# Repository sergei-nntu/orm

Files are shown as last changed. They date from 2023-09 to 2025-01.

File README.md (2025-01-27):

# ORM
Open Robotic Manipulator

# Arduino
Source code: `src/arduino`
Contains the firmware that needs to be installed to Arduino controller.

# Python Library
Soruce code: `src/python`
Contains the python library that allows to communicate with Arduino controller using USB Serial interface. 

# Mechanics
STL Files: `mechanics/ORM-1. PT1/`

# Tests
To run the server tests, use the following command:

```bash
pytest -v

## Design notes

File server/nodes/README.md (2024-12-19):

# ROS 2 Nodes Directory

This directory contains various ROS 2 nodes, which are essential components of the ROS 2 (Robot Operating System) framework. Each node is a standalone executable that performs specific tasks in a robotic system.

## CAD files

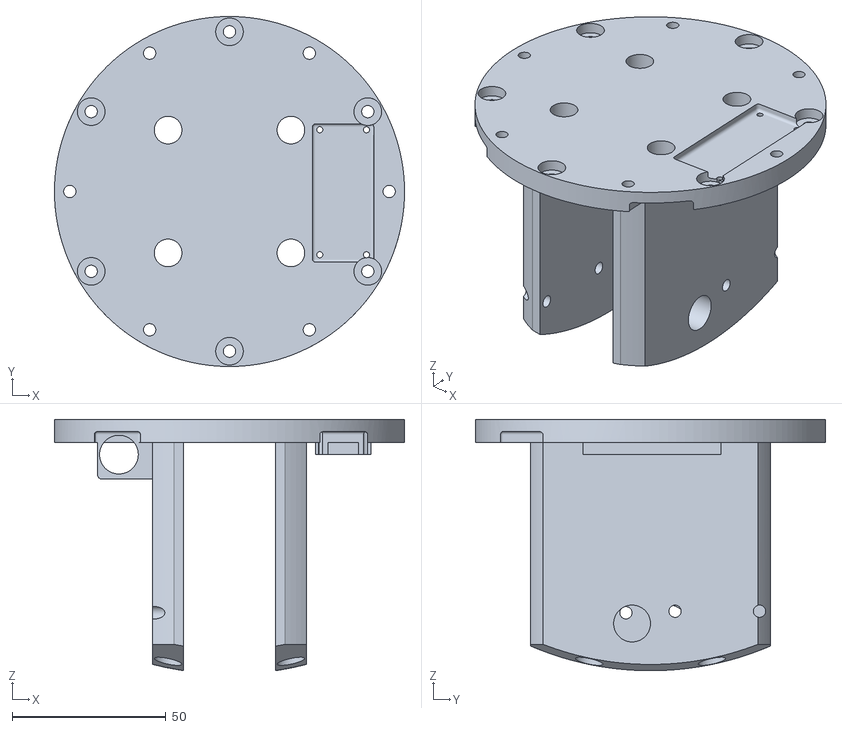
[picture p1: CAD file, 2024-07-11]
mechanics/9_15_3.stl
114.0 x 114.0 x 81.9

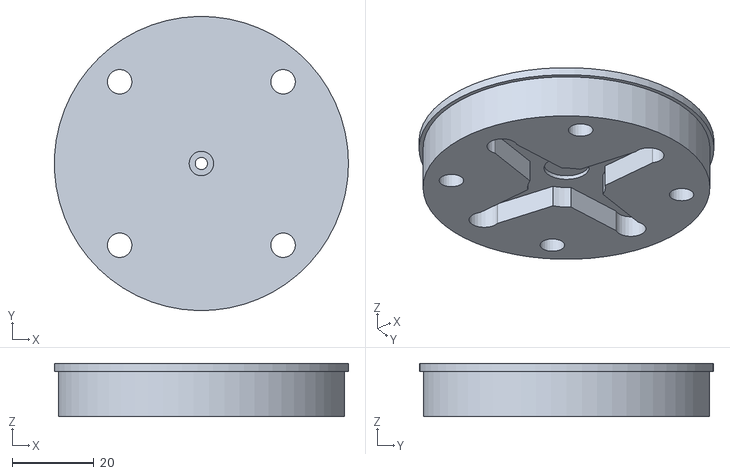
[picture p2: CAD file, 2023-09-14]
mechanics/ORM-1. PT1/15_2_3.stl
71.9 x 72.0 x 13.0

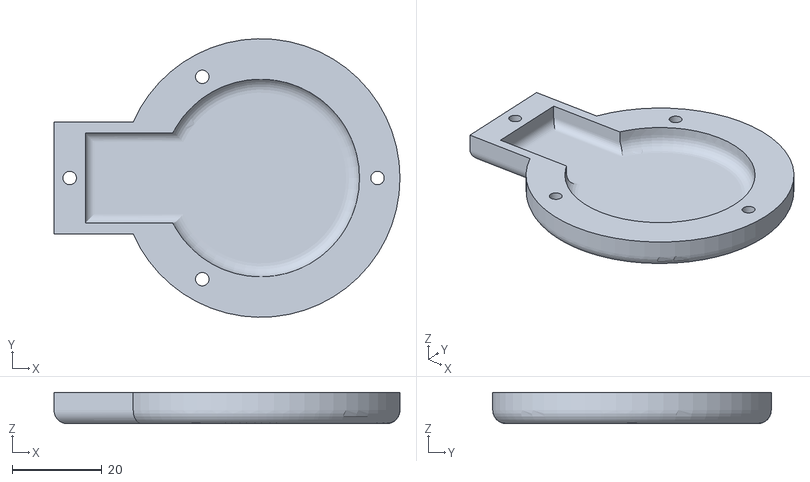
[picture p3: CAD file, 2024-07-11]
mechanics/ORM-1. PT2/14_4_3.stl
77.0 x 62.0 x 7.00

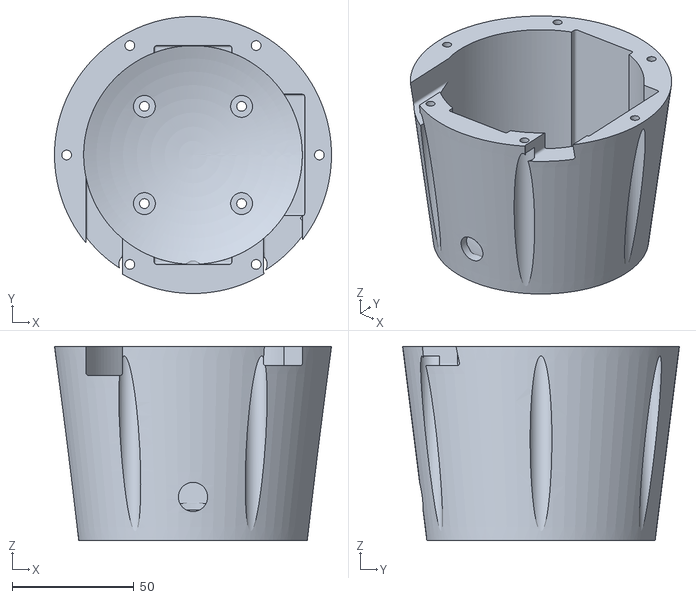
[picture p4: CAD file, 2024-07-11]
mechanics/9_11_4.stl
114.0 x 114.0 x 80.0

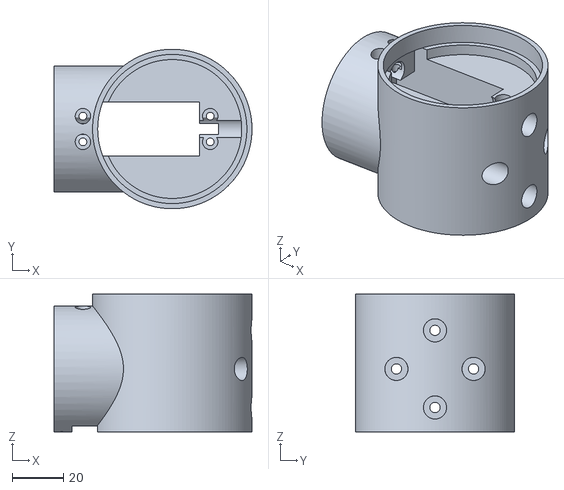
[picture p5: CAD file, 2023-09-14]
mechanics/ORM-1. PT1/14_1_2.stl
77.0 x 62.0 x 53.6

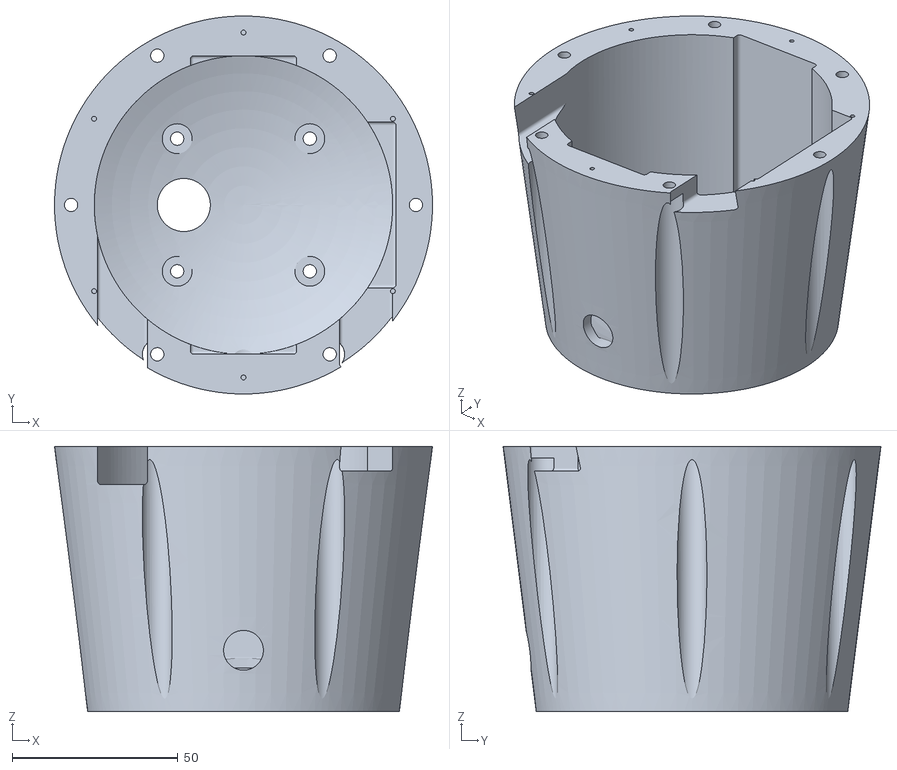
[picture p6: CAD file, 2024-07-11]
mechanics/9_11_5.stl
114.0 x 114.0 x 80.0

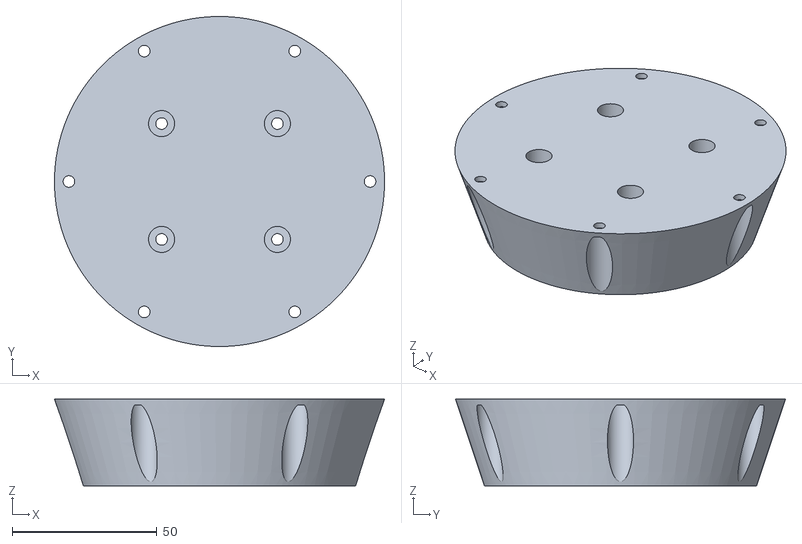
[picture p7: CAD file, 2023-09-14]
mechanics/ORM-1. PT1/9_11_1.stl
114.0 x 114.0 x 30.0

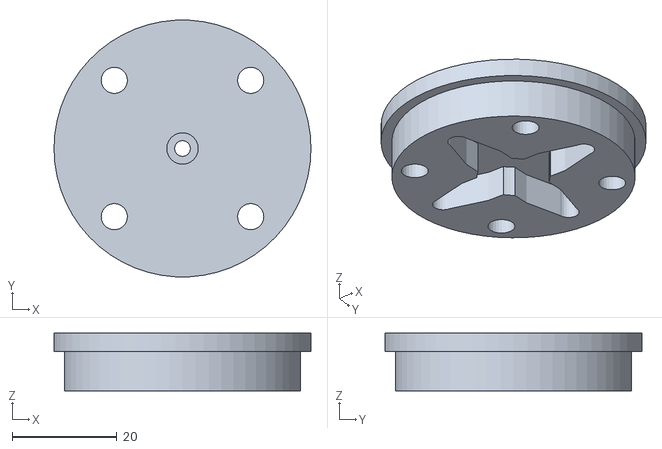
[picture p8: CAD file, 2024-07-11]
mechanics/ORM-1. PT2/14_2_3.stl
49.0 x 48.9 x 11.0

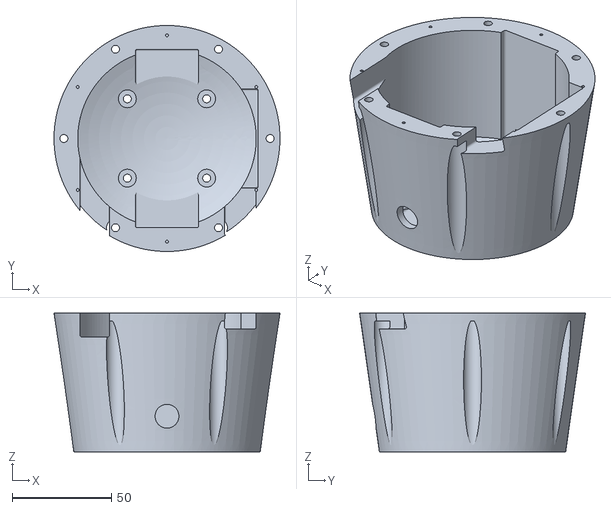
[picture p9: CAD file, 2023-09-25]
mechanics/9_11_3.stl
114.0 x 114.0 x 70.0

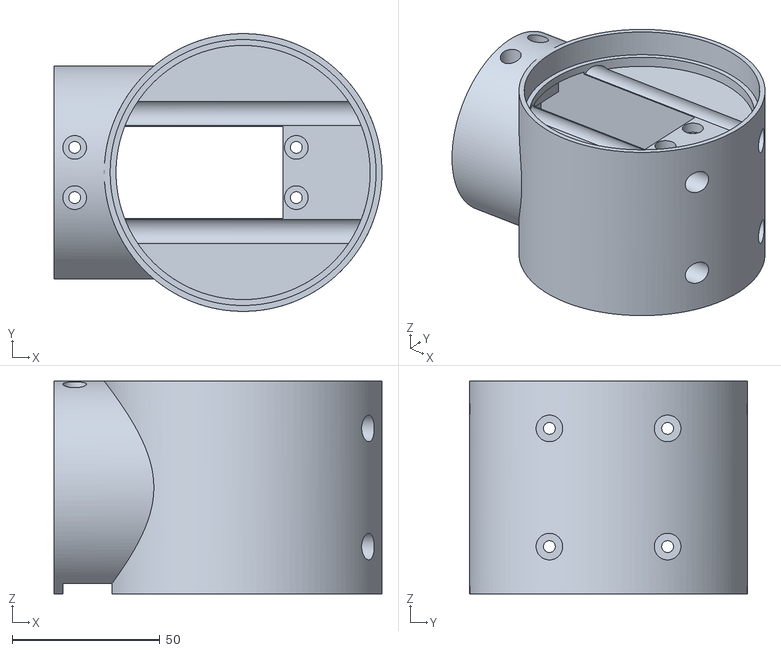
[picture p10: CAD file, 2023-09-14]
mechanics/ORM-1. PT1/15_1_2.stl
111.0 x 94.0 x 72.0

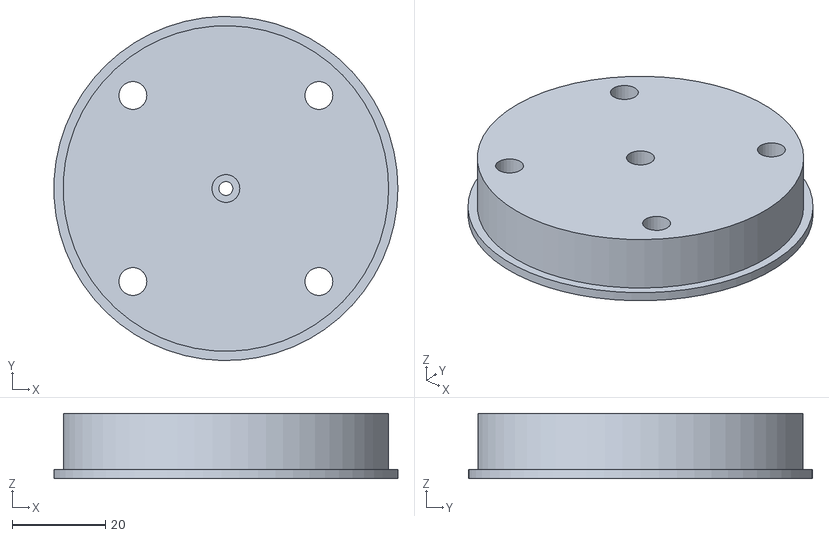
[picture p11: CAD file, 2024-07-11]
mechanics/ORM-1. PT2/15_2_6.stl
73.9 x 74.0 x 14.0

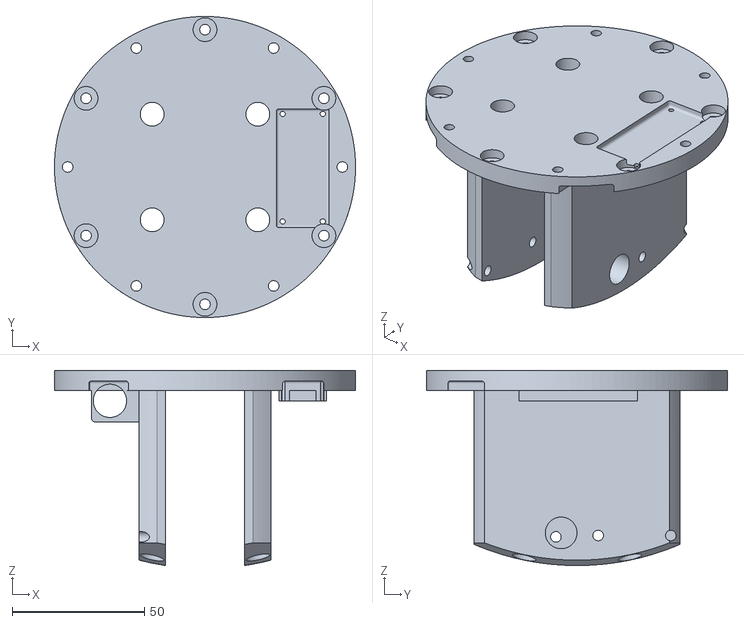
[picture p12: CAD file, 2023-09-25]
mechanics/9_15_2.stl
114.0 x 114.0 x 73.9

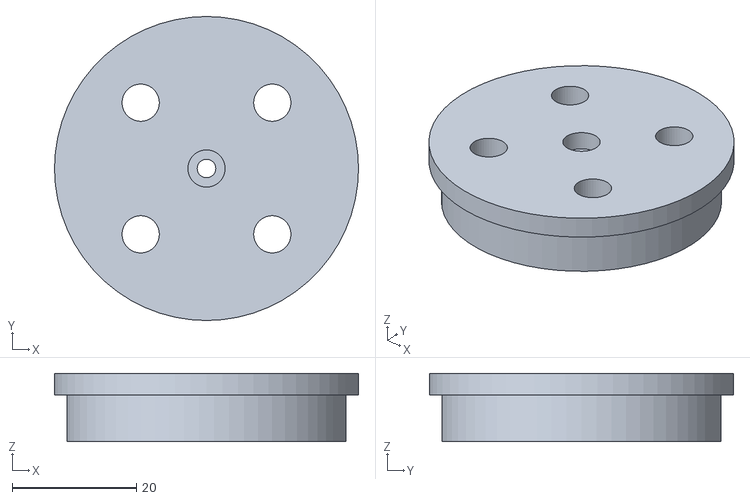
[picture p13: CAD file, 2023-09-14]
mechanics/ORM-1. PT1/14_2_2.stl
49.0 x 49.0 x 11.0

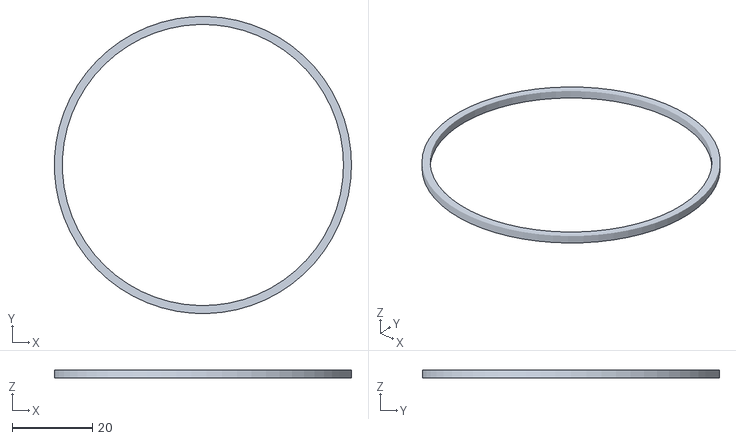
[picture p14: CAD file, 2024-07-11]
mechanics/ORM-1. PT2/15_4_1.stl
74.0 x 74.0 x 2.00

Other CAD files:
mechanics/9_11_2.stl
mechanics/ORM-1. PT2/14_1_6.stl
mechanics/9_13_2.stl
mechanics/9_10_1.stl
mechanics/9_13_1.stl
mechanics/9_14_1.stl
mechanics/9_15_1.stl
mechanics/9_1_2.stl
mechanics/9_4_1.stl
mechanics/9_5_1.stl
mechanics/9_6_1.stl
mechanics/9_7_1.stl
mechanics/9_8_1.stl
mechanics/9_9_1.stl
mechanics/ORM-1 Controller Block.FCStd
mechanics/ORM-1. PT2/15_1_5.stl
mechanics/ORM-1. PT2/15_3_2.stl
mechanics/ShoulderActuator.stl

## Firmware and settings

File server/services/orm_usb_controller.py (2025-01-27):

import sys
import time
import glob
import threading
from osp import OSP
import rospy
from std_msgs.msg import Bool


class USBController:

    def __init__(self):
        self.ports = []
        self.devices = []
        self.osp_dev_type = 1
        self.connection = False

    def process(self):
        self.verify_ports()
        self.logger()
        self.establish_connection()

    def verify_ports(self):
        ports = self.get_os_ports()
        if self.ports_is_not_same(ports):
            self.stop_devices()
            self.connect(ports)
            self.set_ports(ports)

    def connect(self, ports):
        devs = self.get_osp_dev(ports)
        self.get_osp_dev_type(devs)
        self.receive_devs_of_type(devs)
        self.close_devs_of_wrong_type(devs)

    def get_osp_dev(self, ports):
        try:
            devs = list(map(lambda port: OSP(port), ports))
            time.sleep(2)  # Timeout to receive the first messages from the devices
            return devs
        except Exception as err:
            print("Error!!!!", err)
            self.connection = False
            return []

    def get_osp_dev_type(self, devs):
        for dev in devs:
            dev.osp_info_dev_type()
            time.sleep(1)

    def receive_devs_of_type(self, devs):
        self.devices = list(
            filter(lambda d: d.get_dev_type() == self.osp_dev_type, devs)
        )

    def close_devs_of_wrong_type(self, devs):
        devs_of_wrong_type = filter(
            lambda d: d.get_dev_type() != self.osp_dev_type, devs
        )
        for dev in devs_of_wrong_type:
            dev.stop()

    def establish_connection(self):
        self.connection = True if bool(self.devices) else False

    def logger(self):
        print("----------------------------")
        print("Devices:", self.devices)
        print("Ports:", self.ports)
        print("Active threads:", threading.active_count())
        print("----------------------------")

    def set_ports(self, ports):
        self.ports = ports

    def ports_is_not_same(self, ports):
        return self.ports != ports

    def stop_devices(self):
        for dev in self.devices:
            dev.stop()
        time.sleep(1)  # need to close ports

    def get_os_ports(self):
        ports = None
        if sys.platform.startswith("win"):
            ports = ["COM%s" % (i + 1) for i in range(256)]
        elif sys.platform.startswith("linux") or sys.platform.startswith("cygwin"):
            # this excludes your current terminal "/dev/tty"
            lin_ports = glob.glob("/dev/ttyUSB*")
            mac_ports = glob.glob("/dev/tty.usb*")
            ports = lin_ports if not mac_ports else mac_ports
        elif sys.platform.startswith("darwin"):
            ports = glob.glob("/dev/ttyUSB*")
        else:
            raise EnvironmentError("Unsupported platform")
        return ports


if __name__ == "__main__":
    try:
        rospy.init_node("usb_controller")
        usb_publisher = rospy.Publisher("/usb_connection", Bool, queue_size=10)

        usb_controller = USBController()

        rate = rospy.Rate(10)
        while not rospy.is_shutdown():
            usb_controller.process()
            usb_publisher.publish(usb_controller.connection)
            rate.sleep()

    except Exception as err:
        print(f"Unexpected {err=}, {type(err)=}")

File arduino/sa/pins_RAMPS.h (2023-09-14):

#define X_STEP_PIN         54
#define X_DIR_PIN          55
#define X_ENABLE_PIN       38
#define X_MIN_PIN           3
#define X_MAX_PIN           2

#define Y_STEP_PIN         60
#define Y_DIR_PIN          61
#define Y_ENABLE_PIN       56
#define Y_MIN_PIN          14
#define Y_MAX_PIN          15

#define Z_STEP_PIN         46
#define Z_DIR_PIN          48
#define Z_ENABLE_PIN       62
#define Z_MIN_PIN          18
#define Z_MAX_PIN          19

#define E_STEP_PIN         26
#define E_DIR_PIN          28
#define E_ENABLE_PIN       24

#define Q_STEP_PIN         36
#define Q_DIR_PIN          34
#define Q_ENABLE_PIN       30

#define W_STEP_PIN         16
#define W_DIR_PIN          17
#define W_ENABLE_PIN       23

#define SDPOWER            -1
#define SDSS               53
#define LED_PIN            13

#define FAN_PIN            9

#define PS_ON_PIN          12
#define KILL_PIN           -1

#define HEATER_0_PIN       10
#define HEATER_1_PIN       8
#define TEMP_0_PIN          13   // ANALOG NUMBERING
#define TEMP_1_PIN          14   // ANALOG NUMBERING

// AS5600 Encoder Input
#define X_ENCODER_IN      A3
#define Y_ENCODER_IN      A4
#define Z_ENCODER_IN      A5
#define E_ENCODER_IN     A12
#define Q_ENCODER_IN     A9
#define W_ENCODER_IN     A10

#define G0_SERVO_PWM     11

//
// Misc. Functions
//
#define SDSS               53
#define LED_PIN            13

#ifndef FILWIDTH_PIN
  #define FILWIDTH_PIN      5   // Analog Input on AUX2
#endif

// define digital pin 4 for the filament runout sensor. Use the RAMPS 1.4 digital input 4 on the servos connector
#ifndef FIL_RUNOUT_PIN
  #define FIL_RUNOUT_PIN    4
#endif

#ifndef PS_ON_PIN
  #define PS_ON_PIN        12
#endif

//
// Průša i3 MK2 Multiplexer Support
//
#ifndef E_MUX0_PIN
  #define E_MUX0_PIN 40   // Z_CS_PIN
#endif
#ifndef E_MUX1_PIN
  #define E_MUX1_PIN 42   // E0_CS_PIN
#endif
#ifndef E_MUX2_PIN
  #define E_MUX2_PIN 44   // E1_CS_PIN
#endif

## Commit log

2023-02-27 ORM. Added the original implementation of communication betwen PC and Arduino and the control of the stepper motors
2023-04-10 Original Version of Arduino Firmware added. Supports 2 actuators
2023-04-26 ARDUINO: Casted angle for steps, encoder and interface to int angle 0..16384. Added Angle Correction. Implemented statistical encoder data filtering. PYTHON: Casted angle to Int angle for communicati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
    [orm.h, orm.ino, orm_one_ros.py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]
2023-05-16 Mechanics Files Added. Added the support of Int angle for both Arduino and Python source code
    [9_4_1.stl, 9_5_1.stl, 9_6_1.stl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]
2023-05-16 ORM ROS Fix: orm_set_angle is used instead of set_angle to support radians
    [orm_one_ros.py, osp.py]
2023-05-17 Fixed angle sign for orm_set_angle to be compatible with moveit angle system. Took the timing information from the trajectory into account
    [orm_one_ros.py, osp.py]
2023-05-18 Set Speed Function Support on Arduino Side
2023-05-19 Actuators 4 and 5 added. Statistical Filtering of the angle applied. Calibration process optimised
2023-09-05 For a moment ignoring the trajectory. Apply the final joint states immediately. Added Gripper State subscription support
2023-09-05 Added the Support of Servos Instead of Stepper motors for joints
2023-09-05 Added Mechanics Files
    [14_1_2.stl, 14_2_2.stl, 15_1_2.stl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]
2023-09-08 Made acceleration and max speed to be configurable per joint
2023-09-25 Added the small angle threshold to apply the angle change without acceleration
    [9_11_2.stl, 9_11_3.stl, 9_13_2.stl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]
2023-09-28 Added set Angle Width command for the joint. Updated pins numbering to match the Arduino Nano, not Mega with RAMPS 1.4
2023-09-29 Added endpoint GET /current_ip
2023-10-09 Add a new functionality
    - Create a background thread for running blockly code
    - Add the file "program.py" where blockly code is stored
    - Fix end points
    -- start_program - run background thread
    -- stop_program - stop thread
    -- get_program_state - return a id of executed block
    -- set_active_program - get the blockly code and insert it to the file
    - Add should_terminate_flag to stop executing thread
    - Move some logic to other functions for code repeating avoid
    - Add orm functions for executing blockly code
2023-11-23 Add joints state
    * Add joint state subscriber with callback
    * Add endpoint GET /get_joints_state
    * Complete main logic of joints state
2023-11-29 Feature/add route for dog joints (#2)
    * Add dog joint state & Add callback & Add GET function
    * Creating joint publisher & Renaming the route
    * Adding a while loop to publisher & Changing variable names
    ---------
2023-12-05 Feature/post oqp joint state (#4)
    * Adding POST request for OQP
    * Code refactoring
    * Fix error
    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
2024-01-11 Feature/joint trajectory (#8)
    * Subscribe to topic & Get joint trajectory
    * Add /GET endpoint
    * Fix sum of trajectory
2024-01-18 Feature/gripper state (#9)
    * Subscribe to topic and create a callback function
    * fixes
    - fix error with tuple
    - add coefficient of gripper value scale
    * Fixes
    - Remove the constant
    - Comment group.execute cause that's not working correctly
2024-02-29 Add current_pose_state (#10)
2024-03-01 Feature/usb controller (#15)
    * Add usb controller file
    - Update usb controller
    - Add /GET endpoint
    - Add subscriber and publisher for global connection variable
    * Save dev and close it when need
    * Create usb controller class
    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
    [orm_usb_controller.py, osp.py]
2024-04-03 Feature/camera image route (#16)
    * Added video route for manipulator camera
    * Fixed deps, add some refactor
2024-07-11 Added the encoders support and ability to disable motor power for backdriving
    [14_1_6.stl, 14_2_3.stl, 14_4_3.stl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]
2024-12-16 feat: rework project structure
    [orm.h, orm.ino, orm_one_ros.py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]
2024-12-19 feat: implement move joint group client
2024-12-19 fix: move joints client errors
2024-12-23 fix: stupid syntax error
    [blockly.py]
2025-01-21 fix: errors in routes
    [blockly.py]
2025-01-21 fix: remove dup code
    [blockly.py]
2025-01-21 feat: save current program structure
2025-01-22 test: print response_data in every route
2025-01-22 feat: remove unused code, close fixme issues
    [blockly.py]
2025-01-22 fix: remove is_running from the db, routes, etc
    [blockly.py]
